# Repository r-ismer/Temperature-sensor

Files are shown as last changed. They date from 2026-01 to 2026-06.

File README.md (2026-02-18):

# Temperature sensor

This folder contains a hardware, a software part and a mechanical part.  
The hardware part is a KiCad project which contains the schematic and the pcb layout for the temperature and humidity sensor.  
The software part is a make project which contains all the files needed to build the firwmare that will communicate with the temperature and humidity sensor and send these inforamtion to a station (other project).  
The mechanical part is a FreeCAD project which contains the top and bottom casing for the temperature ad humidity sensor.

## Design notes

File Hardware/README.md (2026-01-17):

# Temperature-sensor

## Overview
This project contains the KiCad files for a temperature/humidity sensor.

The temperature and humidity sensor communicates with the STM32F030 thourgh I2C. 

The  programming of the microcontroller can be done through a 19 pin JTAG interface using SWD. 

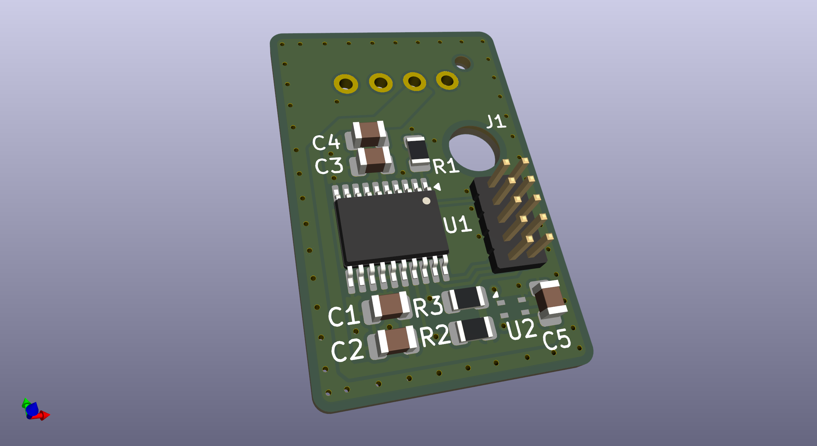
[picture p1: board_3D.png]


## Setup and build

KiCad 9 was used to design the schematic and the PCB. To open the project clone the repository or download the files and open it with KiCad 9.

## Next steps

The next steps are the soldering of all components on the board. Once this is done, the programming part can begin. This consists of: 
- Creating a driver for the SHT4
- Programming the STM32F0 using  the driver

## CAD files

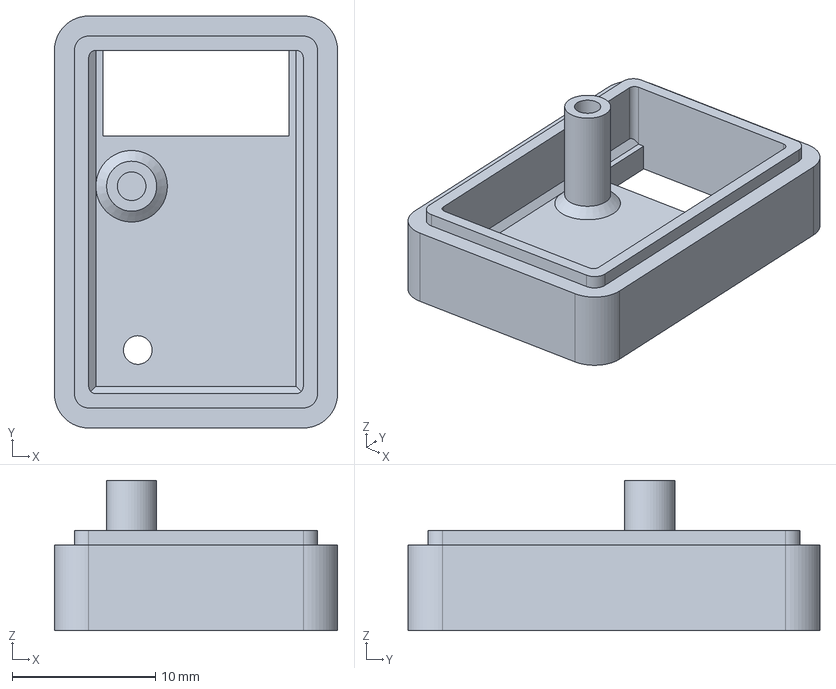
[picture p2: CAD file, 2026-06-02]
Machanical/temperature_sensor_top.FCStd
19.8 x 28.8 x 10.5 mm

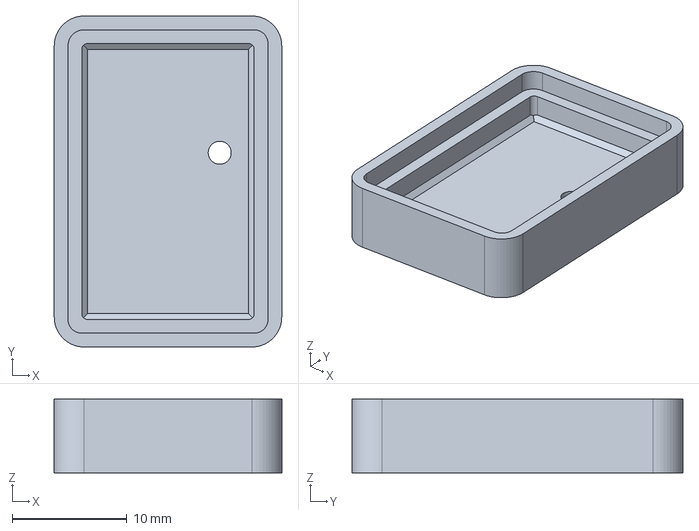
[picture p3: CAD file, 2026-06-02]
Machanical/temperature_sensor_bottom.FCStd
19.8 x 28.8 x 6.40 mm

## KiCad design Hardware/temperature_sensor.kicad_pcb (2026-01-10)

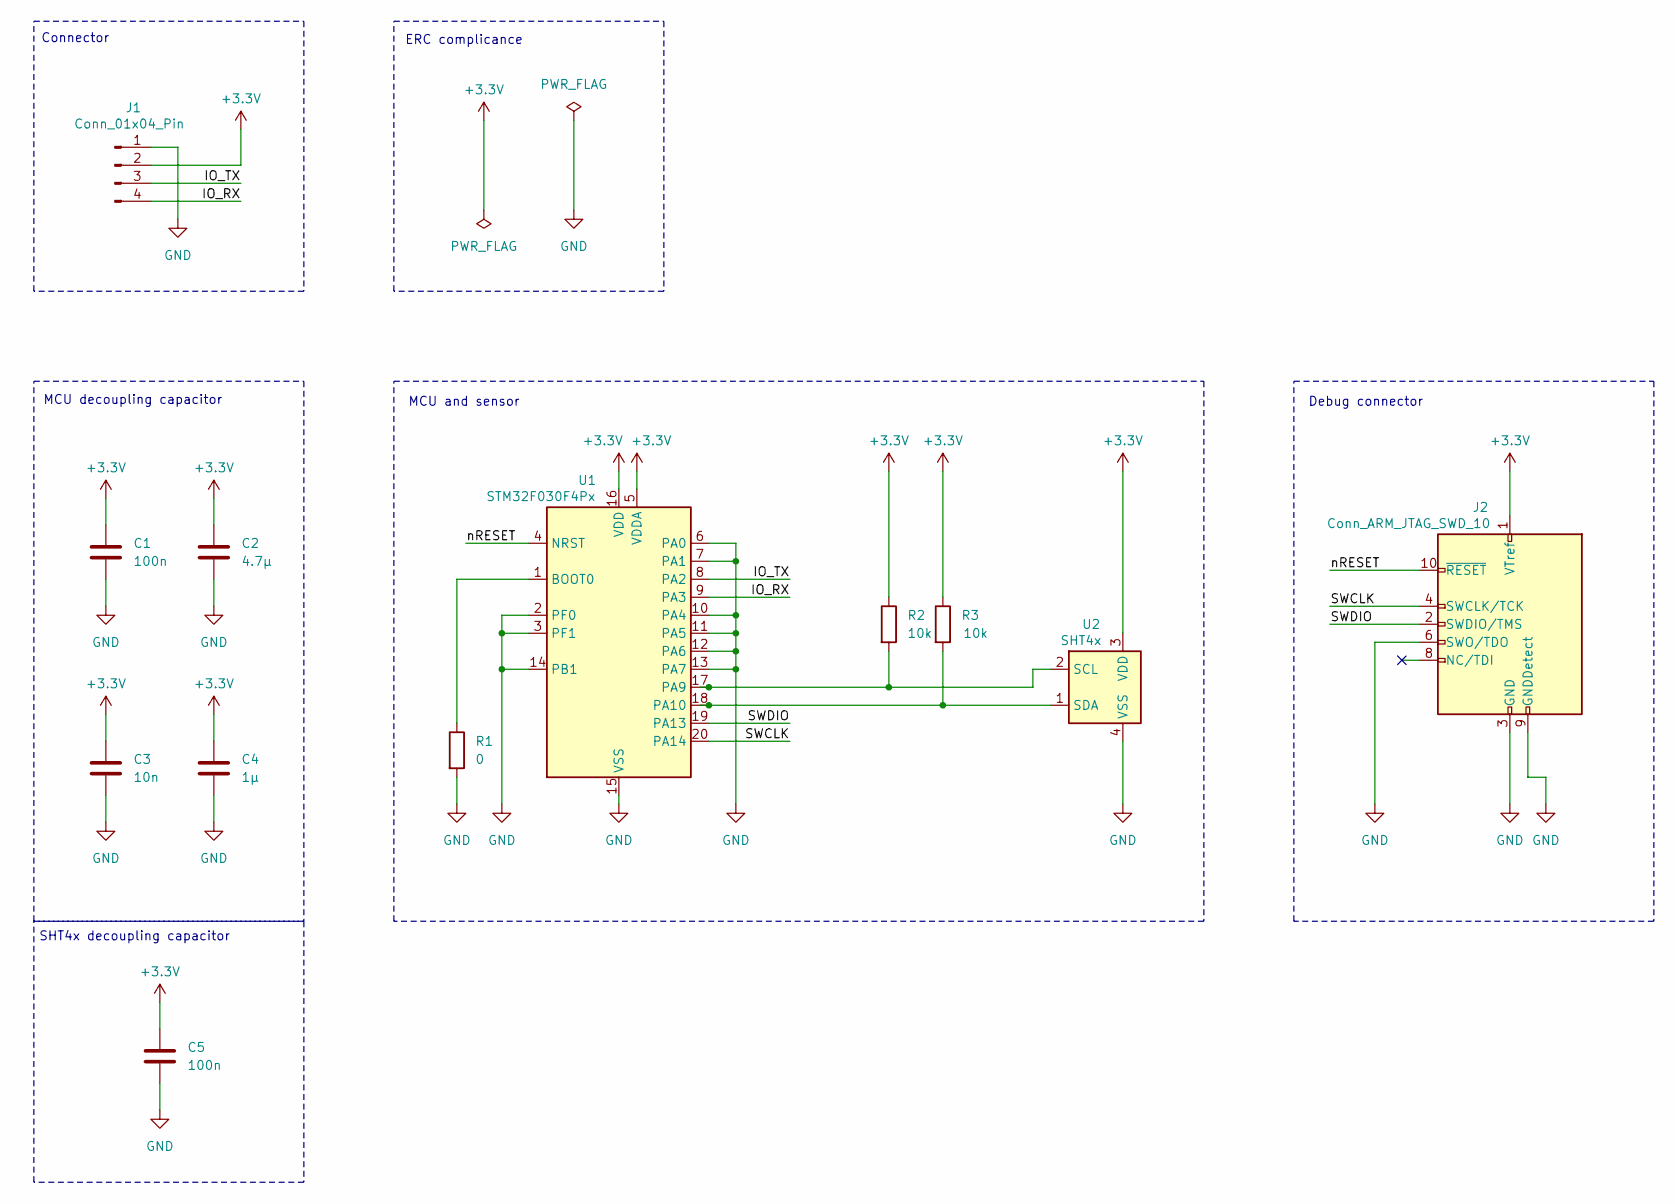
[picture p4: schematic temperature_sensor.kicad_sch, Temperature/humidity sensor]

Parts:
C1, C5: 100n; C_0805_2012Metric
C2: 4.7µ; C_0805_2012Metric
C3: 10n; C_0805_2012Metric
C4: 1µ; C_0805_2012Metric
J1: Conn_01x04_Pin; JST_XA_B04B-XASK-1-A_1x04_P2.50mm_Vertical
J2: Conn_ARM_JTAG_SWD_10; PinHeader_2x05_P1.27mm_Vertical
R1: 0; R_0805_2012Metric
R2, R3: 10k; R_0805_2012Metric
U1: STM32F030F4Px; TSSOP-20_4.4x6.5mm_P0.65mm
U2: SHT4x; Sensirion_DFN-4_1.5x1.5mm_P0.8mm_SHT4x_NoCentralPad

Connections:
+3.3V: C1.1, C2.1, C3.1, C4.1, C5.1, J1.2, J2.1 (VTref), R2.1, R3.1, U1.5 (VDDA), U1.16 (VDD), U2.3 (VDD)
/IO_RX: J1.4, U1.9 (PA3)
/IO_TX: J1.3, U1.8 (PA2)
/SWCLK: J2.4 (SWCLK/TCK), U1.20 (PA14)
/SWDIO: J2.2 (SWDIO/TMS), U1.19 (PA13)
/nRESET: J2.10 (~RESET), U1.4 (NRST)
GND: C1.2, C2.2, C3.2, C4.2, C5.2, J1.1, J2.3 (GND), J2.5 (GND), J2.6 (SWO/TDO), J2.9 (GNDDetect), R1.2, U1.2 (PF0), U1.3 (PF1), U1.6 (PA0), U1.7 (PA1), U1.10 (PA4), U1.11 (PA5), U1.12 (PA6), U1.13 (PA7), U1.14 (PB1), U1.15 (VSS), U2.4 (VSS)
unnamed: R1.1, U1.1 (BOOT0)
unnamed: R2.2, U1.17 (PA9), U2.2 (SCL)
unnamed: R3.2, U1.18 (PA10), U2.1 (SDA)

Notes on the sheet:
ERC complicance
MCU decoupling capacitor
SHT4x decoupling capacitor
Connector
MCU and sensor
Debug connector

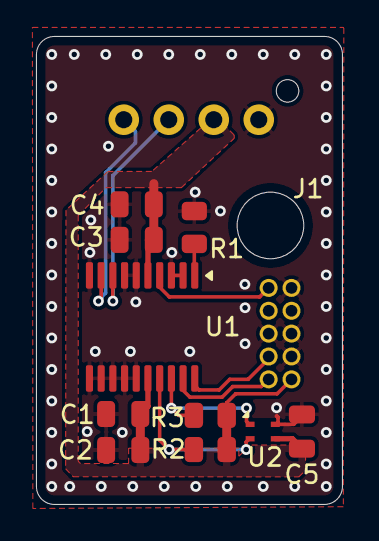
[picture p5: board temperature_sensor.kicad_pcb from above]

Board: 2 copper layers, 17.0 x 26.0 mm, 12 parts (0 on the bottom side), 10 nets.

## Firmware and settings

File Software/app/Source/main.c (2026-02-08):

// **********************************************************************************************************
// File name     : main.c                                                                                   * 
// Author        : Richard I.                                                                               *
// Date          : 30/01/2026                                                                               *
// Description   : Main file                                                                                *
// **********************************************************************************************************
// **********************************************************************************************************
//                                               Include                                                    *
// **********************************************************************************************************
#include "main.h"
#include "task.h"

// **********************************************************************************************************
//                                               Defines                                                    *
// **********************************************************************************************************

// **********************************************************************************************************
//                                              Variables                                                   *
// **********************************************************************************************************

// **********************************************************************************************************
//                                       Private prototype functions                                        *
// **********************************************************************************************************
// **********************************************************************************************************
//                                            Public fuctions                                               *
// **********************************************************************************************************
// **********************************************************************************************************
// Function name    : main                                                                                  *
// Description      : Main function.                                                                        *
// **********************************************************************************************************
int main(void)
{
    // Initialize the HAL library
    HAL_Init();

    // Configure the hardware
    hw_config();

    // Initialize the task
    task_init();

    // Start the timer
    HAL_TIM_Base_Start_IT(&ge_hw_tim_handle);

    // Main loop
    while (1)
    {
        // Disable SysTick
        HAL_SuspendTick();

        // Sleep
        HAL_PWR_EnterSLEEPMode(PWR_MAINREGULATOR_ON, PWR_SLEEPENTRY_WFI);

        // The timer has times out and we can now run the task
        task();
    }
}

// **********************************************************************************************************
// Function name    : error_handler                                                                         *
// Description      : Error handler function.                                                               *
// **********************************************************************************************************
void error_handler(void)
{
    // Infinite loop
    while (1)
    {
        // Break here for debugger
        __asm("bkpt");
    }
}

// **********************************************************************************************************
// Function name    : assert_failed                                                                         *
// Description      : Assert failed function.                                                               *
// **********************************************************************************************************
void assert_failed(uint8_t* file, uint32_t line)
{
    // Infinite loop
    while (1)
    {
        // Break here for debugger
        __asm("bkpt");
    }
}

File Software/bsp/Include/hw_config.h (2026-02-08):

// **********************************************************************************************************
// File name		: hw_config.h                                                                           *
// Author           : Richard I.                                                                            *
// Date				: 30/01/2026                                                                            *
// Description		: Hardware configuration file.                                                          *
// **********************************************************************************************************

# ifndef _HW_CONFIG_H_
# define _HW_CONFIG_H_

// **********************************************************************************************************
//                                               Include                                                    *
// **********************************************************************************************************
#include "main.h"

// **********************************************************************************************************
//                                               Defines                                                    *
// **********************************************************************************************************
// ********************************************** GPIO ******************************************************
// Temperature and huidity sensor
#define TEMP_HUM_SDA_PIN                        GPIO_PIN_10
#define TEMP_HUM_SDA_PORT                       GPIOA

#define TEMP_HUM_SCL_PIN                        GPIO_PIN_9
#define TEMP_HUM_SCL_PORT                       GPIOA

// UART commuication 
#define COM_UART_TX_PIN                         GPIO_PIN_2
#define COM_UART_TX_PORT                        GPIOA

#define COM_UART_RX_PIN                         GPIO_PIN_3
#define COM_UART_RX_PORT                        GPIOA

// ********************************************* TIMER ******************************************************
#define TIM                                     TIM1
#define TIM_PRESCALER                           (59999u)
#define TIM_PERIOD                              (40000u)

// ********************************************** I2C *******************************************************
// Temperature and humidity sensor
#define TEMP_HUM_SENSOR                         I2C1
#define TEMP_HUM_SENSOR_TIMING                  (0x00201D2B)

// ********************************************** UART ******************************************************
// Communication UART
#define COMMUNICATION_UART                      USART1
#define COMMUNICATION_UART_BAUDRATE             (9600u)

// ******************************************* INTERRUPT ****************************************************
// Timer interrupt
#define TIM_IT_IRQ                              TIM1_BRK_UP_TRG_COM_IRQn
#define TIM_IT_IRQ_HANDLER                      TIM1_BRK_UP_TRG_COM_IRQHandler
#define TIM_UP_CALLBACK                         HAL_TIM_PeriodElapsedCallback

// **********************************************************************************************************
//                                           Public variables                                               *
// **********************************************************************************************************
// Global hw handle(s)
extern I2C_HandleTypeDef ge_hw_i2c_handle;
extern UART_HandleTypeDef ge_hw_uart_handle;
extern TIM_HandleTypeDef ge_hw_tim_handle;

// **********************************************************************************************************
//                                            Public fuctions                                               *
// **********************************************************************************************************
// **********************************************************************************************************
// Function name	: hw_config                                                                             *
// Description		: Hardware configuration function.                                                      *
// Argument         : None                                                                                  *
// Return value     : None                                                                                  *
// **********************************************************************************************************
void hw_config(void);

# endif // _HW_CONFIG_H_

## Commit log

2026-01-02 first commmit
    [getting_started.kicad_pcb, getting_started.kicad_sch]
2026-01-02 Changed debug connector footprint
    [getting_started.kicad_sch]
2026-01-02 Updated JST connector
    [getting_started.kicad_pcb, getting_started.kicad_sch]
2026-01-05 Updated schematic and pcb
    [getting_started.kicad_pcb, getting_started.kicad_sch]
2026-01-06 Added power plane
    [getting_started.kicad_pcb]
2026-01-08 Updated planes
    [getting_started.kicad_pcb]
2026-01-08 Pass ERC and DRC
    [getting_started.kicad_pcb, getting_started.kicad_sch]
2026-01-10 Updated pcb layout
    [getting_started.kicad_pcb]
2026-01-17 Updated 3D image of board
2026-01-27 Split hardware and software
    [temperature_sensor.kicad_pcb, temperature_sensor.kicad_sch]
2026-01-29 Tested temperature and humidity sensor
2026-01-30 Created driver for SHT4x
2026-02-08 Added wait for interrupt
2026-02-14 Added files for casing
    [temperature_sensor_bottom.FCStd, temperature_sensor_top.FCStd]
2026-02-18 Updated top casing
    [temperature_sensor_top.FCStd]
2026-03-01 Updated top and bottom mechanical parts
    [temperature_sensor_bottom.FCStd, temperature_sensor_top.FCStd]
2026-03-14 Improved mechanical top and bottom parts
    [temperature_sensor_bottom.FCStd, temperature_sensor_top.FCStd]
2026-03-21 Reworked bottom and top casing after first print
    [temperature_sensor_bottom.FCStd, temperature_sensor_top.FCStd]
2026-06-02 Updated casing for more strenght
    [temperature_sensor_bottom.FCStd, temperature_sensor_top.FCStd]
